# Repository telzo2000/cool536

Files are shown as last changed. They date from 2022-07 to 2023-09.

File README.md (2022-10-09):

# cool536
## What is cool536？

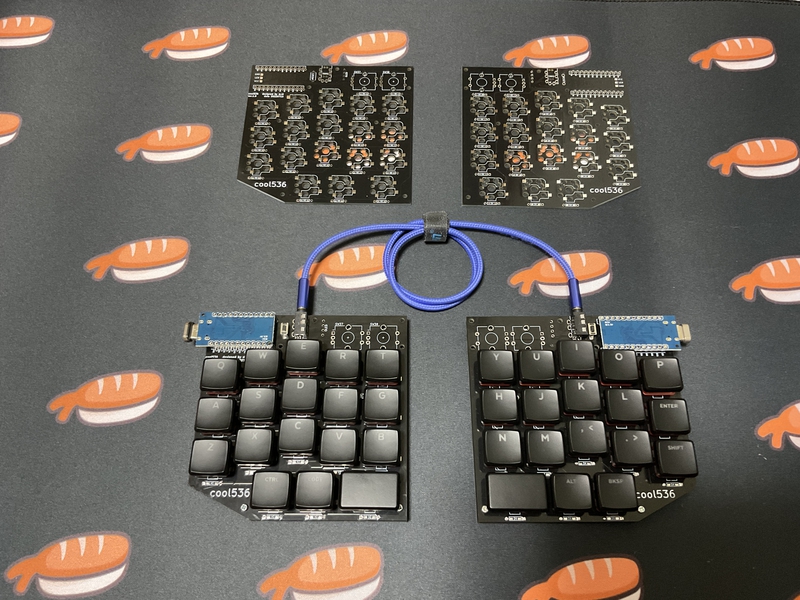
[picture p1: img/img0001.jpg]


The coo536 is a 36-key split keyboard.
<br>
The key layout is column staggered.
<br><br>
coo536は36キーの分割キーボードです。
<br>
キーレイアウトは、カラムスタッガードです。
<br><br>
You can choose either choc switch or cherry mx switch to use.
<br>
Chocスイッチか CHERRY MXスイッチのどちらか一つを選んで使うことができます。
<br>
<br>
Up to 4 rotary encoders can be installed. It is also possible to take an OLED display.
<br><br>
ロータリーエンコーダーを最大4個取り付けることが可能です。また、OLEDディスプレイも取りけることが可能です。
<br>

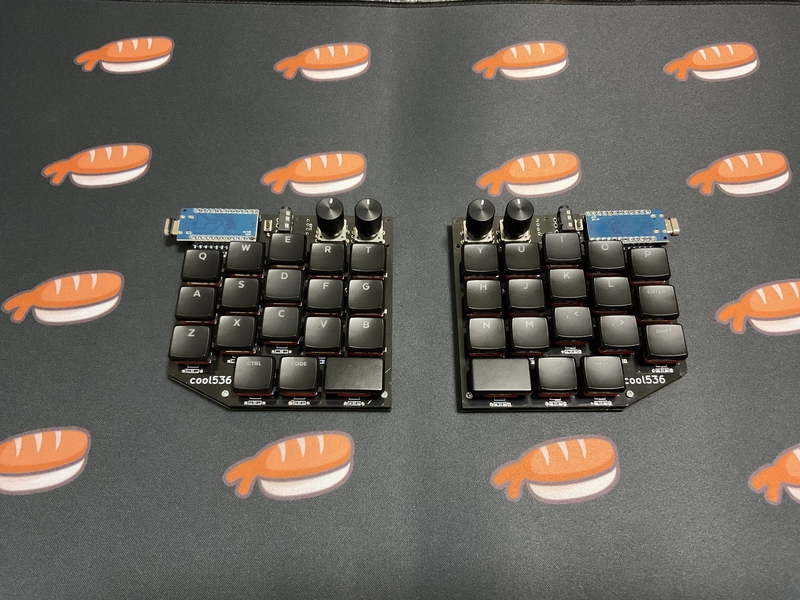
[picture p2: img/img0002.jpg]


<br>
In addition, it is now possible to attach a PIM447 trackball.
<br><br>
さらに、PIM447トラックボールを取り付けることも可能となりました。
<br>
<br>

[PIMORONI PIM447](https://shop.pimoroni.com/products/trackball-breakout?variant=27672765038675)

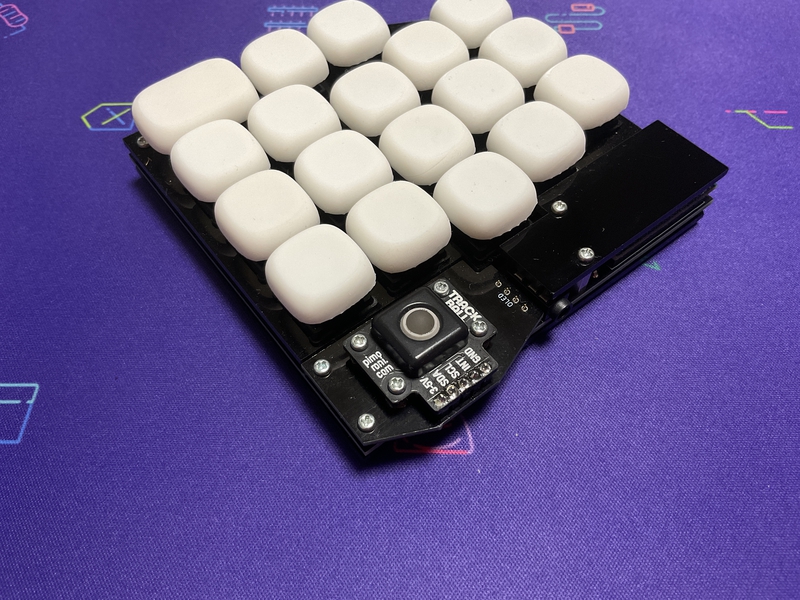
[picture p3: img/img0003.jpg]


<br>
The size of the PCB is within 100mmX100mm.
<br>
It will be distributed on booth in the future, but you can freely use the data here and place an order with the PCB manufacturer.
<br><br>
PCBのサイズは、100mmX100mm以内です。
<br>
将来、boothにて頒布しますが、ここにあるデータを自由に使い、各自がPCB製造元に発注しても構いません。
<br><br>
I do not take any responsibility for the data that you freely use.
<br>
Please use at your own risk.
<br><br>
各自が自由に使ったデータについては、私は一切の責任を負いません。
<br>
自己責任で利用してください。
<br>

## Booth
https://booth.pm/ja/items/4190386

## Build Guide
https://github.com/telzo2000/cool536/blob/main/buildguide_for_cool536.md
<br>

<br>

## Firmware
https://github.com/telzo2000/cool536/tree/main/firmware

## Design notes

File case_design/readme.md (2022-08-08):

The design difference between ver.1.00 and 1.10 is the position of the screw holes in the cover plate.
<br>
ver.1.00と1.10のデザインの違いは、カバープレートのネジ穴の位置が違うことです。
<br>
<br>
From ver.1.10 onwards, the positions of the screw holes on the cover plate have the same design.
<br>
ver.1.10以降は、カバープレートのネジ穴の位置は同じデザインです。
<br>

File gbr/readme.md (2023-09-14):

# gerber file 
<br>

# change history

Ver.1.40 Compatible with [AZ1UBALL](https://booth.pm/ja/items/4202085).
<br>

ver.1.40 [AZ1UBALL](https://booth.pm/ja/items/4202085)に対応。

<br><br>
The PIM447trackball parts are divided into left and right.
<br>
PIM447トラックボール部品は左右に分けました。
<br><br>
ver.1.30 I2C communication failed. Maybe the firmware will fix it.
<br>
ver.1.30 I2C通信をしたが、失敗。多分、ファームウェアで解決する。
<br><br>
ver.1.20　Enlarged screw holes on the pcb.A spacer is passed through from the switch plate to the bottom plate.
<br>
ver.1.20　pcbのネジ穴の拡張した。スイッチプレートからボトムプレートまでスペーサーを通す形式にした。
<br><br>
Ver.1.12　Corresponds to the problem of contact with the PCB wiring due to excessive tightening of the spacer.
<br>
Ver.1.12　スペーサーの締め付け過ぎにより、PCBの配線に接触不具合に対応。
<br><br>
Ver.1.10　Review the screw hole position of the cover plate.
<br>
Ver.1.10　カバープレートのネジ穴位置の見直し。
<br><br>
Ver.1.00　release.
<br>
Ver.1.00　リリース。
<br><br>

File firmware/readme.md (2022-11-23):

If you don't need a rotary encoder,
<br>
<br>
ロータリーエンコーダが不要な場合、
<br>
<br>
https://github.com/telzo2000/cool536/tree/main/firmware/firmware_cool536/cool536<br>
<br>
[remap](https://remap-keys.app)に対応済み。
<br>
<br>
<br>
If you need a rotary encoder,
<br>
<br>
ロータリーエンコーダが必要な場合、
<br>
<br>
https://github.com/telzo2000/cool536/tree/main/firmware/firmware_cool536r<br>
<br>
[remap](https://remap-keys.app)に対応済み。
<br>
<br>
If you need a trackball,
<br>
<br>
トラックボールが必要な場合、
<br>
<br>
https://github.com/telzo2000/cool536/tree/main/firmware/firmware_cool536r<br>
<br>
<br>
[remap](https://remap-keys.app)に対応済み。

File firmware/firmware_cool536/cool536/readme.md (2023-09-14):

# cool536

cool536

*A short description of the keyboard/project*

* Keyboard Maintainer: [m.ki](https://github.com/m.ki)
* Hardware Supported: *The PCBs, controllers supported*
* Hardware Availability: *Links to where you can find this hardware*

Make example for this keyboard (after setting up your build environment):

    make cool536:default

Flashing example for this keyboard:

    make cool536:default:flash

See the [build environment setup](https://docs.qmk.fm/#/getting_started_build_tools) and the [make instructions](https://docs.qmk.fm/#/getting_started_make_guide) for more information. Brand new to QMK? Start with our [Complete Newbs Guide](https://docs.qmk.fm/#/newbs).

## Bootloader

Enter the bootloader in 3 ways:

* **Bootmagic reset**: Hold down the key at (0,0) in the matrix (usually the top left key or Escape) and plug in the keyboard
* **Physical reset button**: Briefly press the button on the back of the PCB - some may have pads you must short instead
* **Keycode in layout**: Press the key mapped to `QK_BOOT` if it is available

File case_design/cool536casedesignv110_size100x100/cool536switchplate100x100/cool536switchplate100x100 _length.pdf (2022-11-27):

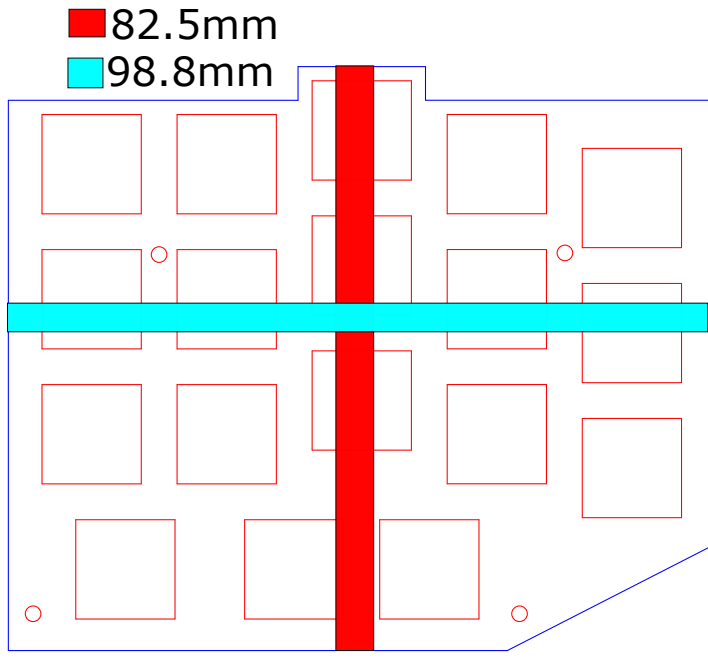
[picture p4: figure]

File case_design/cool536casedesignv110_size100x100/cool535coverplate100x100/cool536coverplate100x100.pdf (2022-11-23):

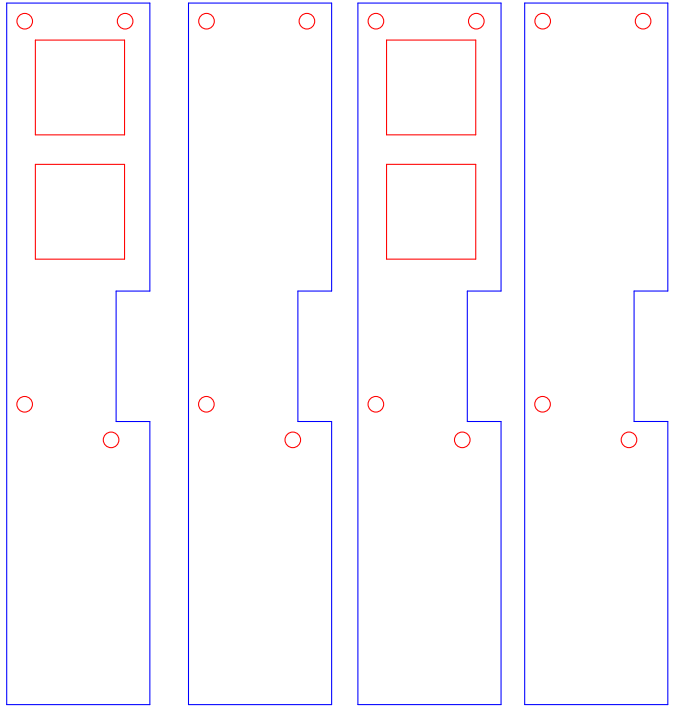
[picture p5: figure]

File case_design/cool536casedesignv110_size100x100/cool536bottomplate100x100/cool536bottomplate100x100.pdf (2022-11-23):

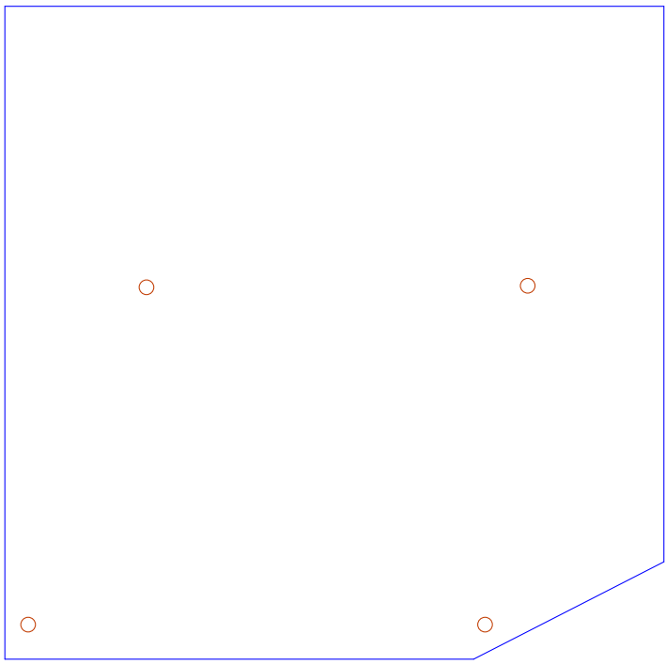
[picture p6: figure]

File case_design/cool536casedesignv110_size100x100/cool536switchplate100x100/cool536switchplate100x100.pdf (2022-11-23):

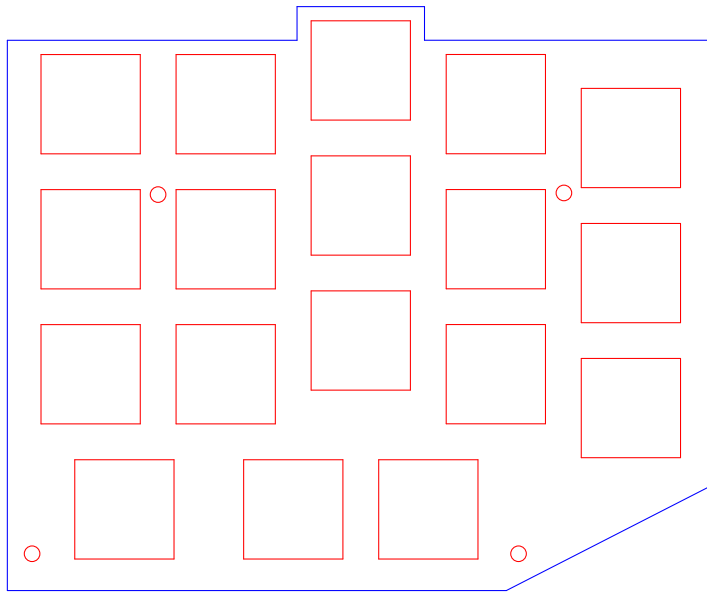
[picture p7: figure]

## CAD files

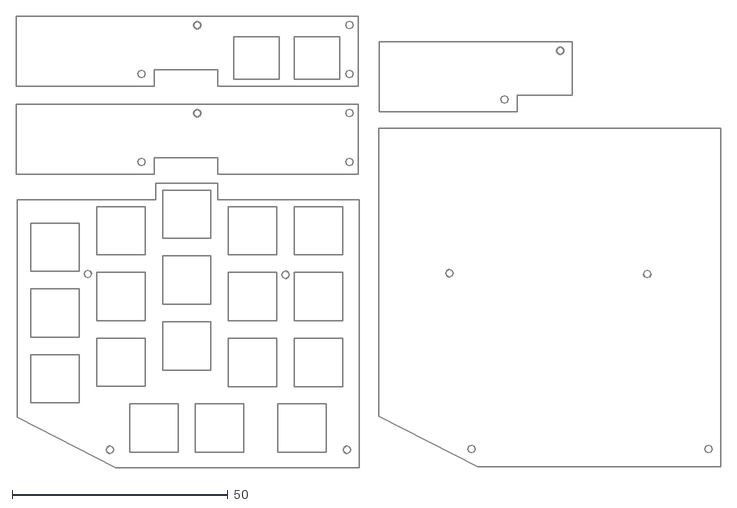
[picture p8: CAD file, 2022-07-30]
case_design/cool536casedesignv100/cool536casedesign200x300.dxf
163.1 x 104.5

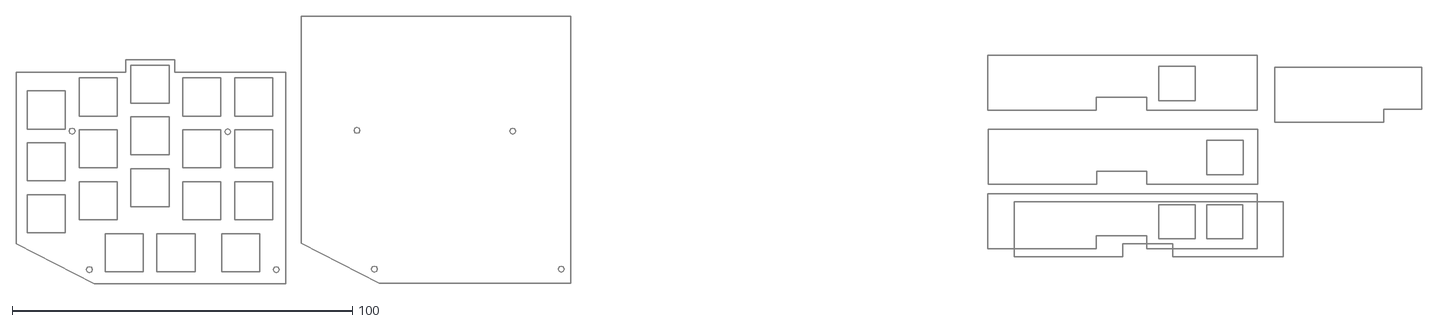
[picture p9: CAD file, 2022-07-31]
case_design/cool536casedesignv110/cool536casedesign240x280.dxf
413.0 x 78.6

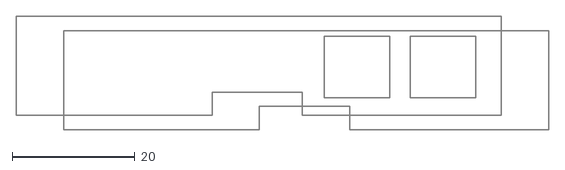
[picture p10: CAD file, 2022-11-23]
case_design/cool536casedesignv110_size100x100/cool535coverplate100x100/cool536coverplate100x100.dxf
86.9 x 18.5

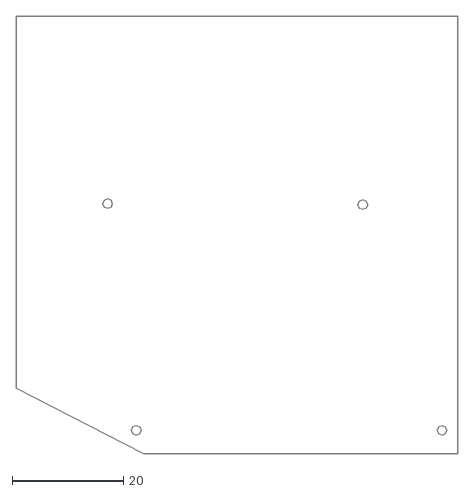
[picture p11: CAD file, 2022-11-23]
case_design/cool536casedesignv110_size100x100/cool536bottomplate100x100/cool536bottomplate100x100.dxf
79.2 x 78.4

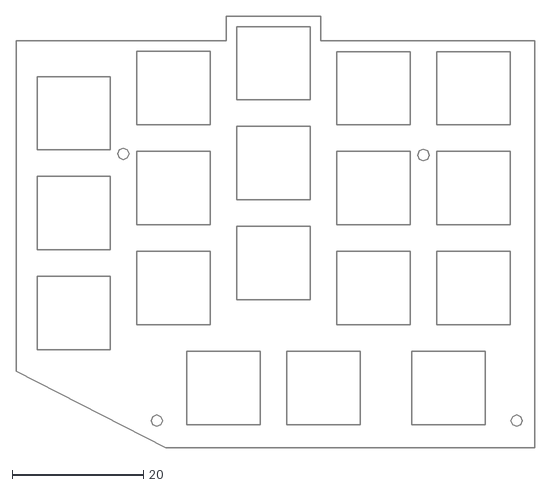
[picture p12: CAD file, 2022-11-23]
case_design/cool536casedesignv110_size100x100/cool536switchplate100x100/cool536switchplate100x100.dxf
79.2 x 65.9

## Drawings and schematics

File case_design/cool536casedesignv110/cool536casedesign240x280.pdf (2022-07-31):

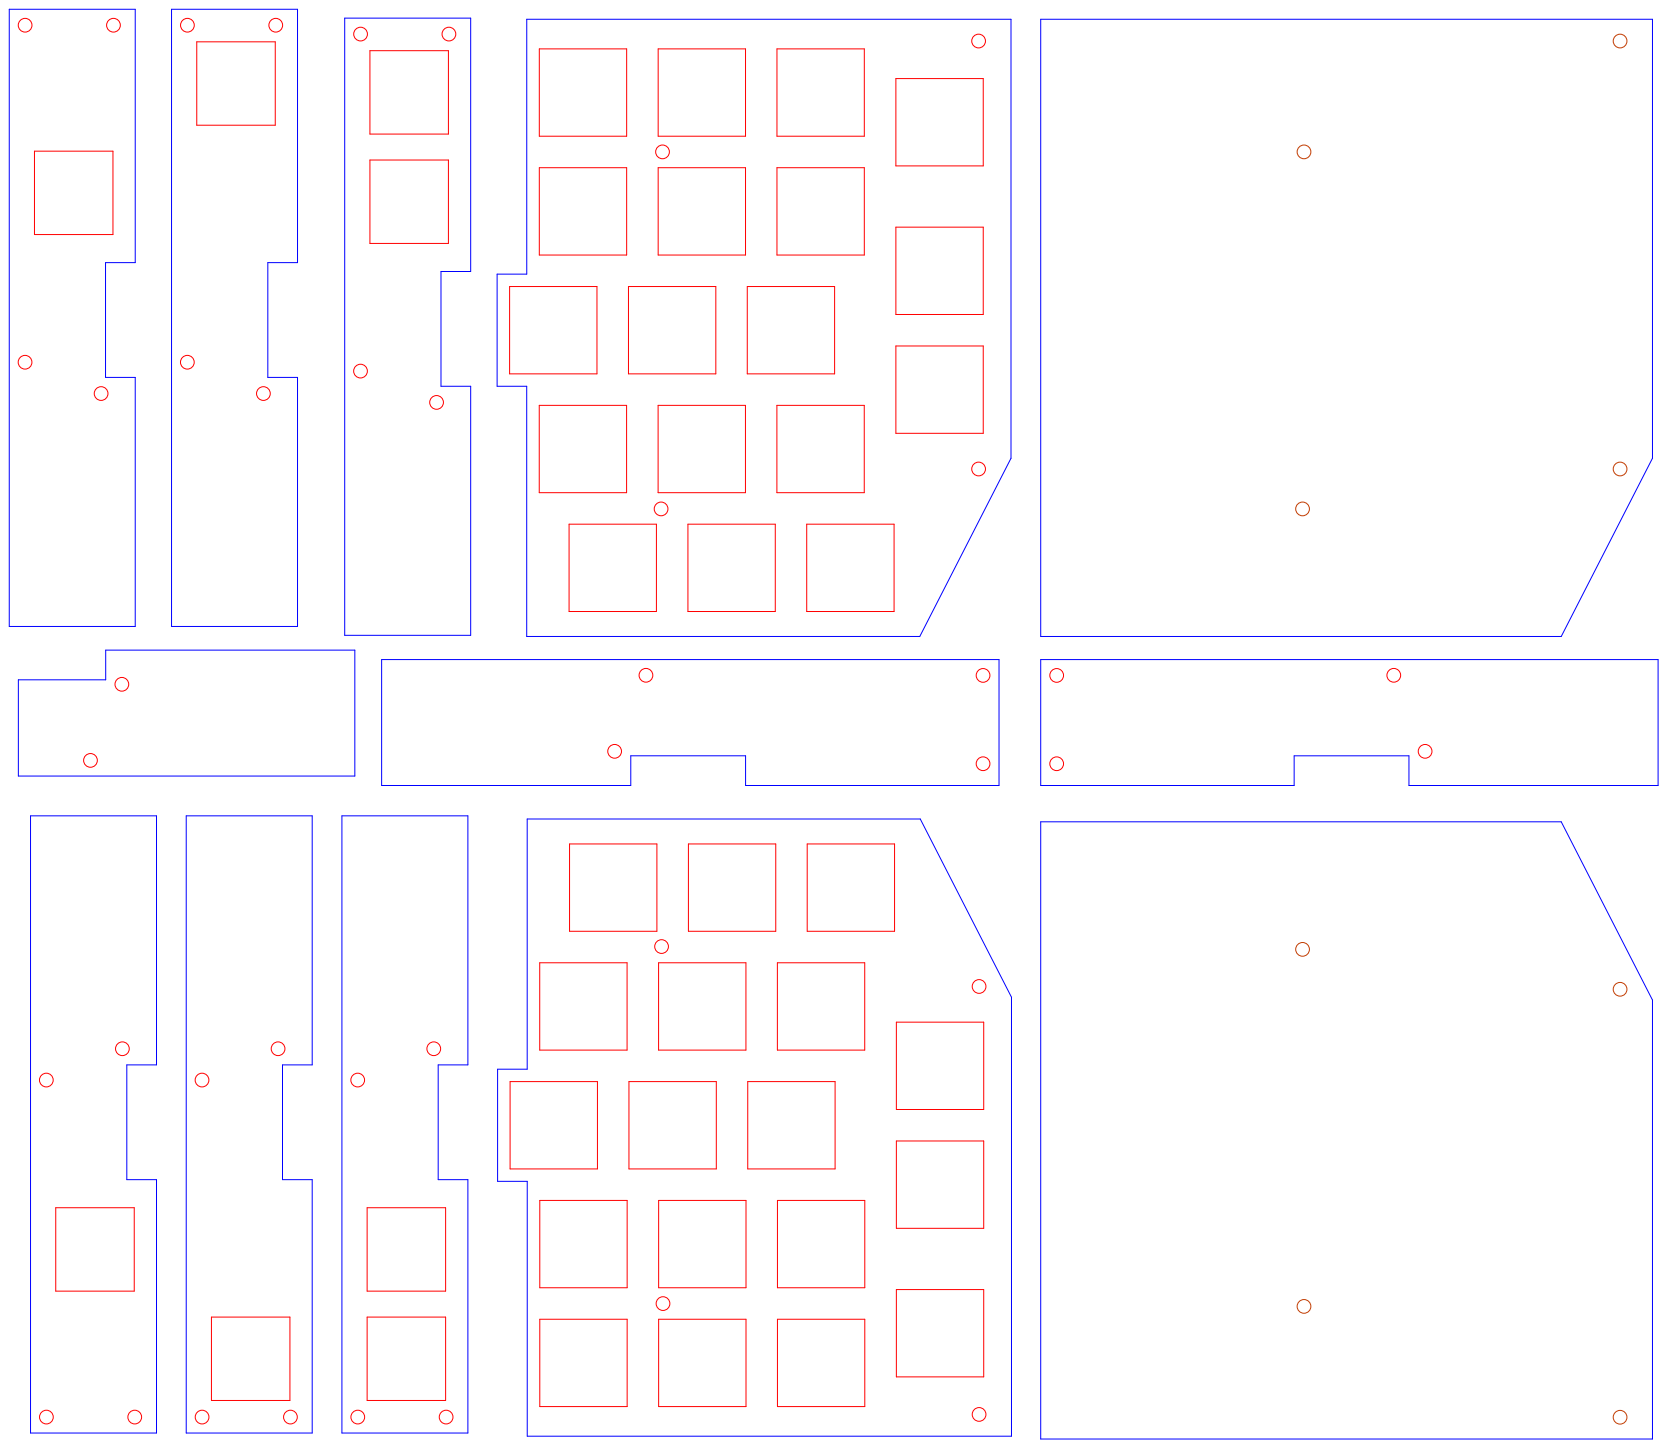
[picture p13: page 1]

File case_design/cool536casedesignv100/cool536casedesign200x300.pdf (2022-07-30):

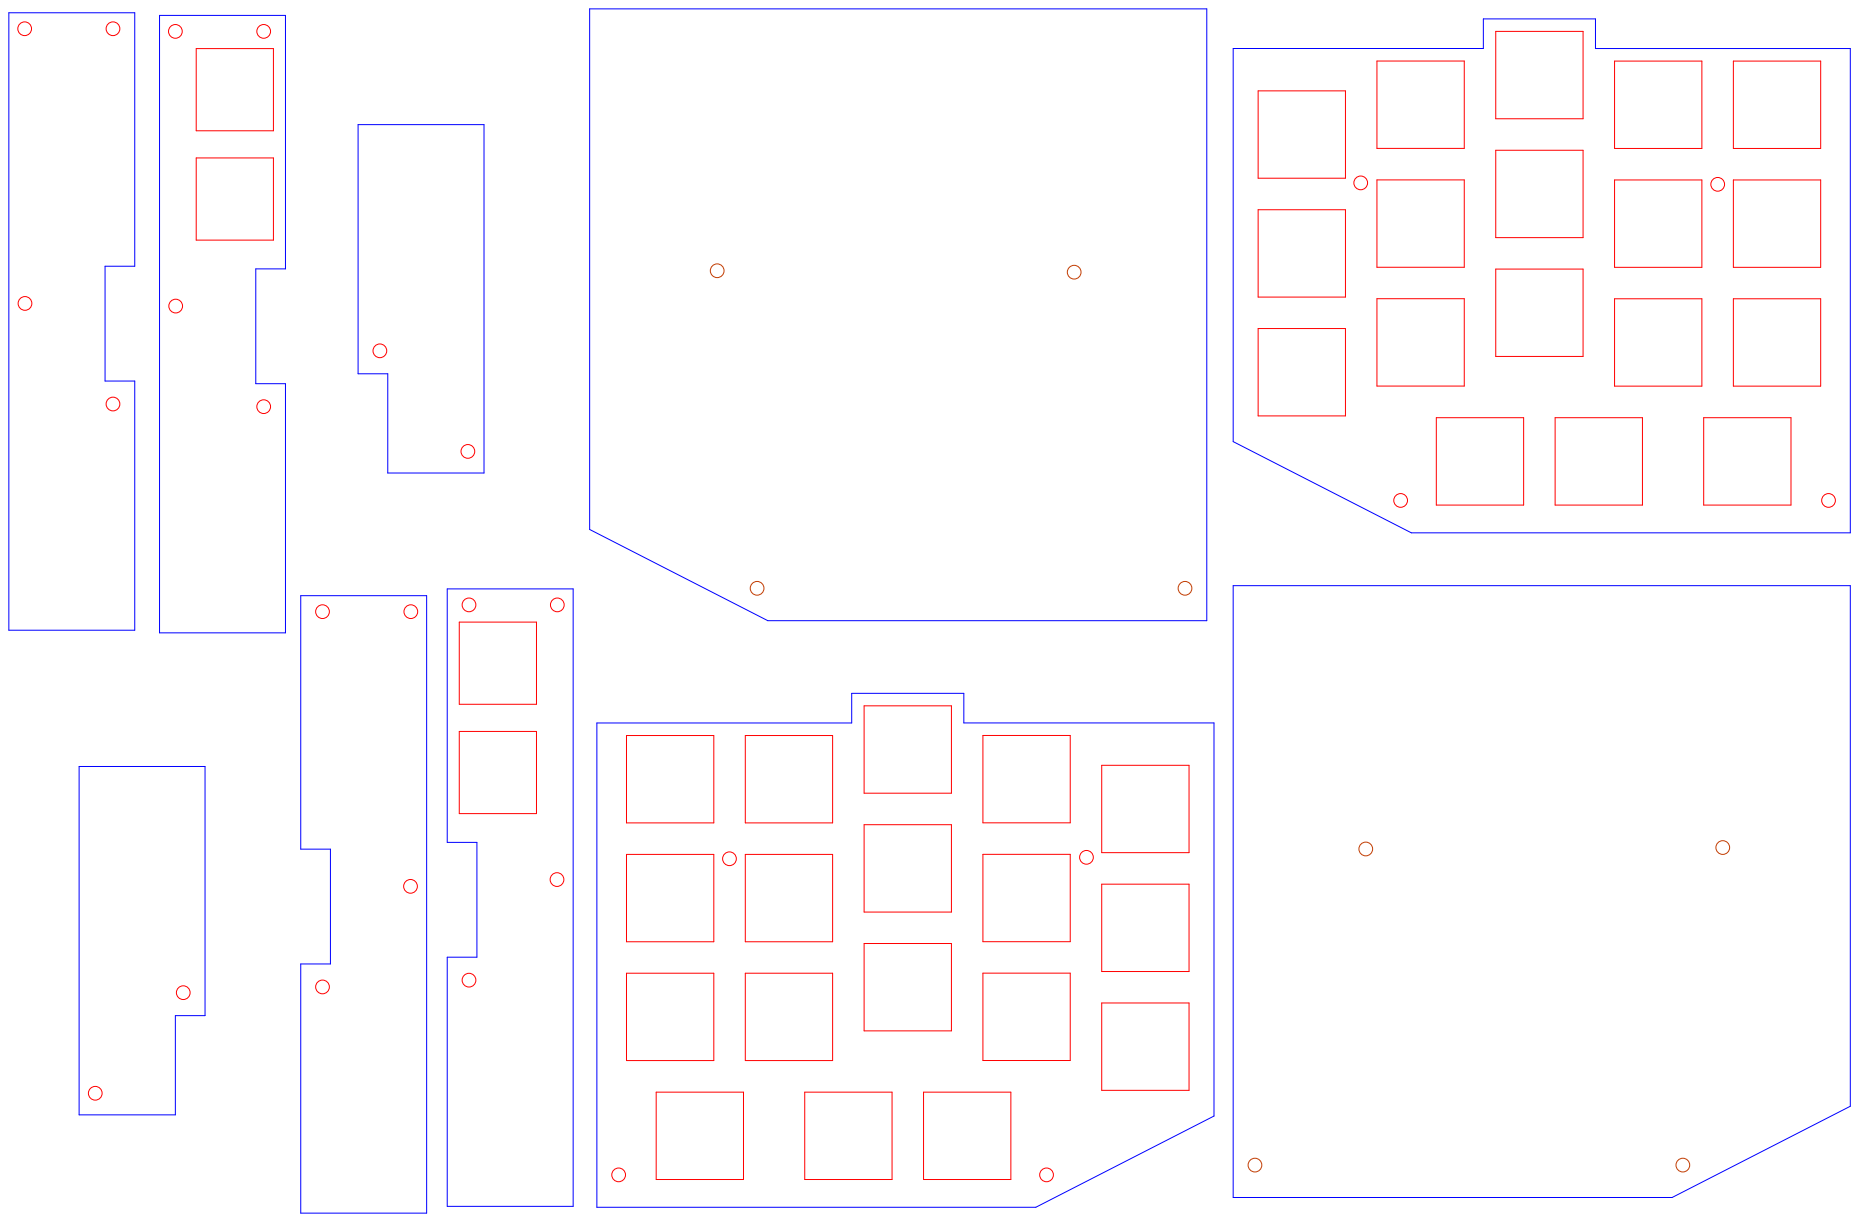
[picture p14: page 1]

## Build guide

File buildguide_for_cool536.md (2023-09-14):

# Build guide

## Parts list

| No. | Patrs | Quantity | remarks | Suppliers | Cost |
|--|--|--|--|--|--|
|番号|名前|数|備考|調達先|参考価格（送料込）|<br>
|1|PCB|2|40%splite keyboard|[elecrow](https://www.elecrow.com)<br>[JLCPCB](https://jlcpcb.com)<br>[ALLPCB](https://www.allpcb.com)|５枚で10〜20ドル|<br>
|2-1|Switch Plate<br>スイッチプレート|2|アクリル<br>[Plate data](https://github.com/telzo2000/cool536/tree/main/case_design)|[工房Emerge+](https://www.emergeplus.jp/laser-cutting-service/contact/)<br>[遊舎工房](https://yushakobo.jp)<br>[elecrow](https://www.elecrow.com)|種類による。|
|2-2|Cover Plate<br>カバープレート|2|↑|↑|↑|
|2-3|Bottom Plate<br>ボトムプレート|2|↑|↑|↑|
|3|M2screw<br>M2ネジ|16|4mm<br>CoverPlateで使用<br>3mmでも代用可|DIYショップなど|10本で100円程度|
|4|M2screw<br>M2ネジ|8|3mm<br>BottomPlateで使用|↑|↑|
|5A|M2screw<br>M2ネジ|8|8mm<br>MXスイッチ使用時SwitchPlateで使用|↑|↑|
|5B|M2screw<br>M2ネジ|8|6mm<br>chocスッチ使用時SwitchPlateで使用|↑|↑|
|6A|M2spacer<br>M2スペーサー|16|3mmメス-メス<br>MXスイッチ使用時|[ヒロスギネット](https://www.hirosugi-net.co.jp/shop/c/c10/)<br>[遊舎工房](https://yushakobo.jp)|20本で800円程度|
|6B|M2spacer<br>M2スペーサー|8|3mmメス-メス<br>chocスイッチ使用時|[ヒロスギネット](https://www.hirosugi-net.co.jp/shop/c/c10/)<br>[遊舎工房](https://yushakobo.jp)|20本で800円程度|
|7|M2spacer<br>M2スペーサー|8|8mmメス-メス<br>CoverPlateで使用|[ヒロスギネット](https://www.hirosugi-net.co.jp/shop/c/c10/)<br>[遊舎工房](https://yushakobo.jp)|20本で800円程度|
|8|pro micro|2|ピンヘッダも別途購入|[遊舎工房](https://yushakobo.jp)<br>[Talp Keyboard](https://talpkeyboard.net)<br>[Daily Craft Keyboard](https://shop.dailycraft.jp)等|価格変動中|
|9A|Swith socket<br>スイッチソケット|36|cherry MX互換|[遊舎工房](https://yushakobo.jp)<br>[Talp Keyboard](https://talpkeyboard.net)<br>[Daily Craft Keyboard](https://shop.dailycraft.jp)等|10個で165円程度|
|9B|Swith socket<br>スイッチソケット|36|choc互換|[遊舎工房](https://yushakobo.jp)<br>[Talp Keyboard](https://talpkeyboard.net)<br>[Daily Craft Keyboard](https://shop.dailycraft.jp)等|10個で165円程度|
|10|Diode<br>ダイオード|40|リードタイプでもSMDでも可|[遊舎工房](https://yushakobo.jp)<br>[Talp Keyboard](https://talpkeyboard.net)<br>[Daily Craft Keyboard](https://shop.dailycraft.jp)等|100個で220円程度から|
|11|タクトスイッチ|2|２本足のもの|[遊舎工房](https://yushakobo.jp)<br>[Talp Keyboard](https://talpkeyboard.net)<br>[Daily Craft Keyboard](https://shop.dailycraft.jp)等|１個11円程度|
|12|TRRSジャック|2|MJ-4PP-9|[遊舎工房](https://yushakobo.jp)<br>[Talp Keyboard](https://talpkeyboard.net)<br>[Daily Craft Keyboard](https://shop.dailycraft.jp)等|１個55円|

In addition, you will need a TRRS cable, USB cable, keycaps, etc.
<br>
この他に、TRRSケーブル、USBケーブル、キーキャップ等が必要です。
<br>
For ver.1.20 PCB, 4 M2spacer 8mm are required instead of 6A, and 4 M2spacer 5mm are required instead of 6B.
<br>
ver.1.20のPCBでは、6Aの代わりにM2spacer8mmを４本、6Bの代わりにM2spacer5mmを４本、必要となります。
<br>

## Firmware

###  QMK_FIRMWARE
[Here](https://github.com/telzo2000/cool536/tree/main/firmware)

<br>
[remap](https://remap-keys.app/)

<br>

## Build 1(PCB only)

### 1 Parts check

The cool536 is a PCB that uses both the front and back sides for left and right PCBs.
<br>
The part where the corner is cut diagonally will be the outside of the left and right.
<br>
<br>
cool536は左右のPCBに対して、表裏両面を使用するPCBです。
<br>
角が斜めにカットされている箇所が、左右の外側になります。
<br>

### 2 Diode soldering

Solder the diodes to the back of each of the left and right.
<br>
左右それぞれの裏面にダイオードのハンダ付けをします。
<br>

There are lead type and SMD diodes.
<br>
ダイオードはリードタイプか、SMDがあります。
<br>
Here, we will explain the lead type soldering.
<br>
ここでは、リードタイプのハンダ付けの説明をします。
<br>
However, those who adopt the choc switch should use SMD diodes.
<br>
ただし、chocスイッチを採用する人は、SMDのダイオードを使用してください。
<br>

Use a lead bender to bend the legs of the diode.
<br>
リードベンダーを使い、ダイオードの足を曲げます。
<br>

Insert the diode into the board.
<br>
ダイオードを基板に挿しこみます。
<br>

Please pay attention to the orientation of the diode.
<br>
ダイオードの向きに注意してください。
<br>

Secure the diode with masking tape, then face up.
<br>
マスキングテープでダイオードを固定してから、表面を上にします。
<br>
Solder the protruding legs.
<br>
はみ出ている足部分に、ハンダ付けをします。
<br>
After soldering, use nippers to cut off the protruding legs.
<br>
はんだ付けが終わったら、はみ出ている足をニッパーで切り取ってください。
<br>

[８倍速　Diodeハンダ付け動画](https://youtu.be/Yaodh2-XxV4)

<br>
<br>

### 3 Soldering switch sockets

Solder the switch sockets on the back side.
<br>
裏面にスイッチソケットのハンダ付けをします。
<br>
cool536 is compatible with both choc and cherry MX switches.
<br>
cool536はchocスイッチとcherryMXスイッチの両方に対応しています。
<br>
Both can be installed.
<br>
両方を取り付けることが可能です。
<br>
Here, solder the cherryMX switch.
<br>
ここでは、cherryMXスイッチのハンダ付けを行います。
<br>
Place the switch socket so that the letters MX are hidden.
<br>
MXという文字が隠れるように、スイッチソケットを乗せてください。
<br>
That is the correct switch socket orientation.
<br>
それが正しいスイッチソケットの向きになります。
<br>
When using a choc switch, place the switch socket so that the letters choc are hidden.
<br>
chocスイッチの時は、chocという文字が隠れるように、スイッチソケットを乗せてください。
<br>

Apply solder to both pads.
<br>
両方のパッドにハンダを盛ります。
<br>
Place the switch socket and fix it with a warm soldering iron while melting the solder.
<br>
スイッチソケットを乗せて、温めたハンダゴテで、ハンダを溶かしながら、固定します。
<br>
You can make it easier by working while holding it with tweezers.
<br>
ピンセットで押さえながら、作業をすると楽にできます。
<br>

[８倍速　Switch socketハンダ付け動画](https://youtu.be/E__mHvmIXQo)

<br><br>

### 4 Soldering reset switch & TRRS jack 

Insert the reset switch on the surface.
<br>
表面にリセットスイッチを挿しこみます。
<br>
Solder the legs of the reset switch from the back.
<br>
裏面からリセットスイッチの足をハンダ付けします。
<br>
Solder the TRRS jack in the same way near the reset switch.
<br>
TRRSジャックは、リセットスイッチの近くに同じようにハンダ付けします。
<br>
Insert the left and right TRRS jacks from the front side and solder from the back side.
<br>
TRRSジャックは左右１箇所ずつ、表面から差し込み、裏面からはんだ付けをしてください。
<br>

[８倍速　Reset switch,TRRS jackハンダ付け動画](https://youtu.be/3gEbExaOAv4)

<br><br>

### 5　Pro micro 

cool536 requires pro micro on each side.
<br>
cool536は左右それぞれにpro microが必要となります。
<br>

Use the conthrough to fix the pro micro with the side with the parts facing down.
<br>
pro microの部品のある面を下向きに、コンスルーを使い、固定してください。
<br>

Pay attention to the orientation of the conthrough.
<br>
コンスルーの向きに注意してください。
<br>

<br>

### 6　Test

Please write the firmware and check the operation.
<br>
ファームウェアを書き込んで、動作確認をしてください。
<br>

Install a switch or measure continuity with tweezers, etc.
<br>
スイッチを取り付けるか、ピンセット等で導通をはかるかを行います。
<br>

<br>

### QMK_FIRMWARE
[Here](https://github.com/telzo2000/cool536/tree/main/firmware)

<br>
[remap](https://remap-keys.app/)
<br>
<br>

### 7 Installation of key switch

Attach your favorite key switch.
<br>
好きなキースイッチを取り付けてください。
<br>

<br>
If you like, attach a rubber cushion to the back and you're done.
<br>
お好みで裏面にラバークッションを取り付けたら、完成です。
<br>
<br>
<br>

### Option 1 Installing a rotary encoder

cool536 can be equipped with 1 to 2 rotary encoders on the left and right, for a total of 4 rotary encoders.
<br>
cool536は、左右に１〜２個、合計４個のロータリーエンコーダーを取り付けることができます。
<br><br>

### Option 2 Mounting the OLED display

The left side of the cool536 can be fitted with an OLED display.
<br>
In that case, the rotary encoder cannot be attached to the left side of the cool536.
<br>
cool536の左側には、OLEDディスプレイを取り付けることができます。
<br>
その場合、cool536の左側には、ロータリーエンコーダーを取り付けることができません。
<br>
<br>

### OPtion 3 Installing PIM447 Trackball

You can install the PIM447 on either the left or right side.
<br>
In that case, you will need trackballpart.
<br><br>
左右どちらでも、PIM447を取り付けることができます。
<br>
その時は、trackballpartが必要となります。
<br>
<br>
In addition to PIM447 and trackballpart, you will need １２ M2 screws, 6 M2 spacers 3mm, and a pin header.
<br><br>
PIM447とtrackballpartの他に、M2ネジ3mm12本、M2スペーサー3mm６個、ピンヘッダが必要となります。
<br><br>

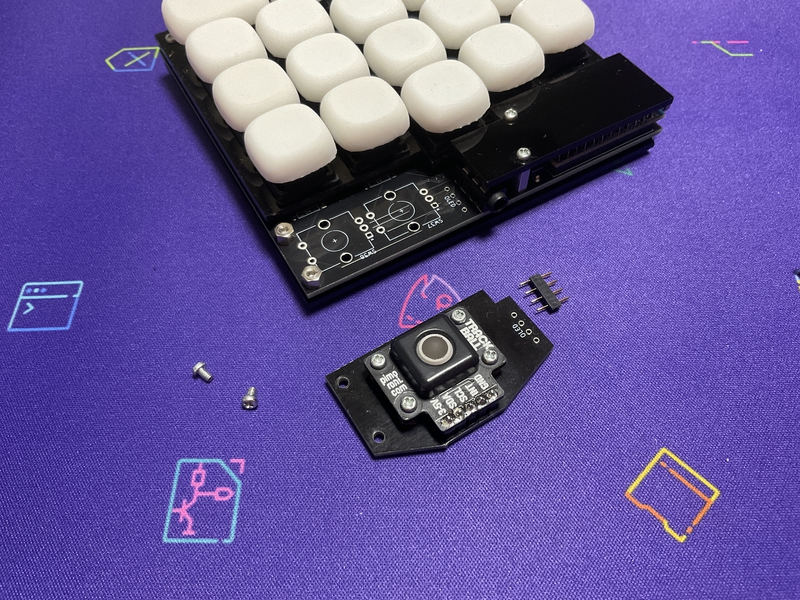
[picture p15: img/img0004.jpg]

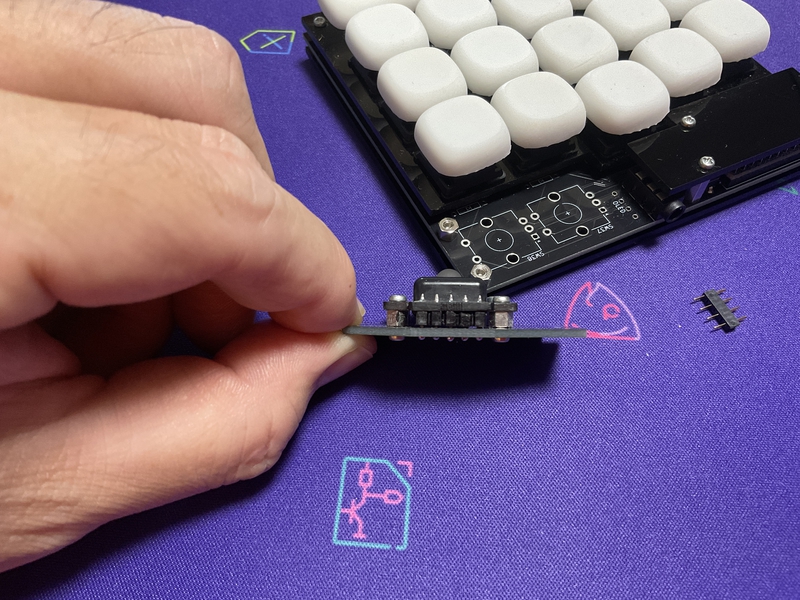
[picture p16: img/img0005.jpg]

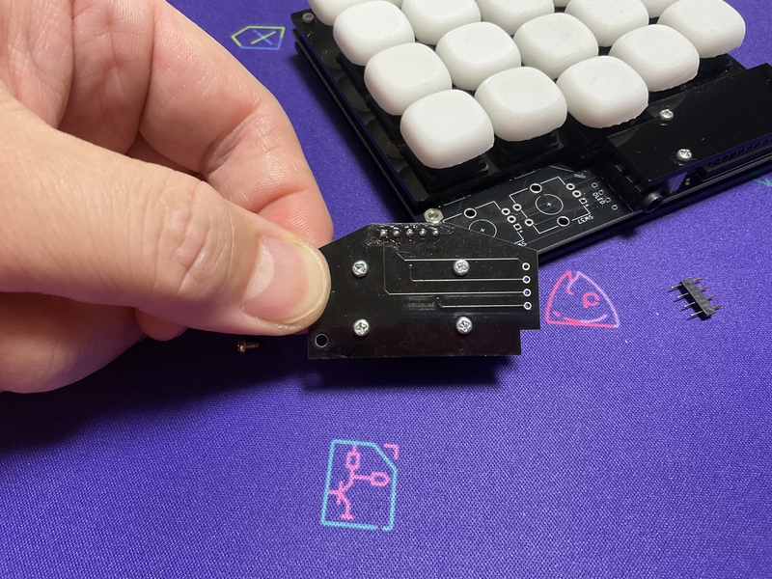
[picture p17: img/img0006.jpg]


<br><br><br>

## Build 2(Acrylic sandwich mount case)



After 1 ~ 6 of build1, please do the next step.
<br>
build1の1~6の後、次の工程をしてください。
<br>

### 1 Installation of cover plate

Prepare a cover plate, M2 spacer 8mm（x４）, and M2 screw 4mm（x８）.
<br>
カバープレート、M2スペーサー6mm（４個）、M2ネジ3mm（８本）を用意します。
<br>
Screw the spacer to the cover plate in the same orientation.
<br>
カバープレートに同じ向きで、スペーサーをネジで固定します。
<br>
Then use the remaining screws to attach the cover plate to the PCB.
<br>
次に、残りのネジを使い、カバープレートをPCBに取り付けます。
<br>
There is an orientation of the cover plate, so it is good to check it once before starting work.
<br>
カバープレートの向きがあり、作業前に一度、重ねて確認すると良いです。
<br>
<br>
A special cover plate is required when installing a rotary encoder or an OLED display.
<br>
ロータリーエンコーダーまたはOLEDディスプレイを取り付けているとき、専用のカバープレートが必要となります。
<br><br>

### 2-1 Installation of switch plate（choc switch）

Prepare a switch plate, M2 spacer 3 mm（x４）, and M2 screw 6 mm（x４）.
<br>
スイッチプレート、M2スペーサー３mm（４本）、M2ネジ６mm（４本）を用意します。
<br>
Fix the screws in 4 places.
<br>
ネジを４箇所、固定します。
<br>
Insert the screws in the order of the switch plate and the PCB, and fix them with spacers on the back of the PCB.
<br>
ネジはスイッチプレート、PCBの順でさしこみ、PCBの裏面でスペーサーで固定します。
<br>

<br>

### 2-2 Installation of switch plate（cherry MX switch）

Prepare a switch plate, M2 spacer 3 mm（x８）, and M2 screw 8 mm（x４）.
<br>
スイッチプレート、M2スペーサー３mm（８本）、M2ネジ８mm（４本）を用意します。
<br>
Fix the screws in 4 places.
<br>
ネジを４箇所、固定します。
<br>
Insert the switch plate into the screw and fix it with a spacer.
<br>
ネジはスイッチプレートをさしこみ、スペーサーで固定します。
<br>
Next, insert the switch plate into the PCB and secure it with a spacer on the back of the PCB.
<br>
次に、スイッチプレートをPCBにさしこみ、PCBの裏面でスペーサーで固定します。
<br>

### 3 Installation of bottom plate 

Prepare the bottom plate and M2 ３mm screws（x４）.
<br>
ボトムプレート、M２ネジ３mm（４本）を用意します。
<br>
Place the bottom plate according to the spacer on the back of the PCB and fix it with screws.
<br>
PCB裏面にあるスペーサーに合わせて、ボトムプレートをのせて、ネジで固定します。
<br>
<br>
From here, proceed with step 7 of build1.
<br>
ここからは、build１の７の工程を進めてください。
<br>

Have a fun selfmade keyboard life!
<br>
楽しい自作キーボード生活を!

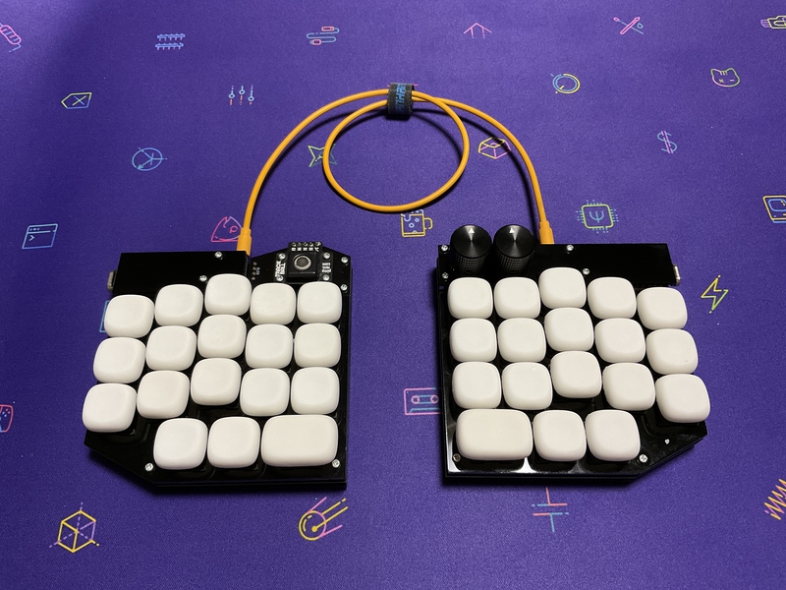
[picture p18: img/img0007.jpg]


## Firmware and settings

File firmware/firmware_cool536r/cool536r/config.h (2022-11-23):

// Copyright 2021 m.ki (@telzo2000)
// SPDX-License-Identifier: GPL-2.0-or-later

#pragma once

#include "config_common.h"

/* USB Device descriptor parameter */
#define VENDOR_ID    0x4D43
#define PRODUCT_ID   0x0537
#define DEVICE_VER   0x0001
#define MANUFACTURER m.ki
#define PRODUCT      cool536r

/* key matrix size */
#define MATRIX_ROWS 10
#define MATRIX_COLS 5

#define MATRIX_ROW_PINS { B5, B4, B1 , F7, D0 }
#define MATRIX_COL_PINS { B2, B6, B3, F6, F5 }
#define MATRIX_ROW_PINS_RIGHT { B5, B4, B1 , F7, D0 }
#define MATRIX_COL_PINS_RIGHT { B2, B6, B3, F6, F5  }
#define UNUSED_PINS

#define DIODE_DIRECTION ROW2COL

#define ENCODERS_PAD_A {D4,D7 }
#define ENCODERS_PAD_B {C6,E6 }
#define ENCODERS_PAD_A_RIGHT {D7,D4 }
#define ENCODERS_PAD_B_RIGHT {E6,C6}

#define MASTER_LEFT

#define SOFT_SERIAL_PIN D2
//#define SELCT_SOFT_SERIAL_SPEED {4}
//#define USE_I2C
#define MASTER_LEFT
#define SPLIT_OLED_ENABLE

#define SPLIT_USB_DETECT

#define RGB_DI_PIN D3
#ifdef RGB_DI_PIN
#    define RGBLED_NUM 16
#    define RGBLIGHT_HUE_STEP 8
#    define RGBLIGHT_SAT_STEP 8
#    define RGBLIGHT_VAL_STEP 8
#    define RGBLIGHT_LIMIT_VAL 255 /* The maximum brightness level */
#    define RGBLIGHT_SLEEP  /* If defined, the RGB lighting will be switched off when the host goes to sleep */
/*== all animations enable ==*/
#    define RGBLIGHT_ANIMATIONS
/*== or choose animations ==*/
//#    define RGBLIGHT_EFFECT_BREATHING
//#    define RGBLIGHT_EFFECT_RAINBOW_MOOD
//#    define RGBLIGHT_EFFECT_RAINBOW_SWIRL
//#    define RGBLIGHT_EFFECT_SNAKE
//#    define RGBLIGHT_EFFECT_KNIGHT
//#    define RGBLIGHT_EFFECT_CHRISTMAS
//#    define RGBLIGHT_EFFECT_STATIC_GRADIENT
//#    define RGBLIGHT_EFFECT_RGB_TEST
//#    define RGBLIGHT_EFFECT_ALTERNATING
/*== customize breathing effect ==*/
/*==== (DEFAULT) use fixed table instead of exp() and sin() ====*/
//#    define RGBLIGHT_BREATHE_TABLE_SIZE 256      // 256(default) or 128 or 64
/*==== use exp() and sin() ====*/
#    define RGBLIGHT_EFFECT_BREATHE_CENTER 1.85  // 1 to 2.7
#    define RGBLIGHT_EFFECT_BREATHE_MAX    255   // 0 to 255
#endif

/* Debounce reduces chatter (unintended double-presses) - set 0 if debouncing is not needed */
#define DEBOUNCE 5

/* define if matrix has ghost (lacks anti-ghosting diodes) */
//#define MATRIX_HAS_GHOST

/* Mechanical locking support. Use KC_LCAP, KC_LNUM or KC_LSCR instead in keymap */
#define LOCKING_SUPPORT_ENABLE
/* Locking resynchronize hack */
#define LOCKING_RESYNC_ENABLE

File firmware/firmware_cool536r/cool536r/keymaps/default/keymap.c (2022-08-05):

// Copyright 2022 m.ki (@telzo2000)
// SPDX-License-Identifier: GPL-2.0-or-later

#include QMK_KEYBOARD_H

// Defines names for use in layer keycodes and the keymap
enum layer_names {
  _QWERTY,
    _LOWER,
    _RAISE,
    _ADJUST,
};

// Defines the keycodes used by our macros in process_record_user
enum custom_keycodes {
    QWERTY = SAFE_RANGE,
    LOWER,
    RAISE,
    ADJUST,
};

const uint16_t PROGMEM keymaps[][MATRIX_ROWS][MATRIX_COLS] = {
    
    [_QWERTY] = LAYOUT(
    KC_1,    KC_2,                                                                                  KC_3,    KC_4,
    KC_Q,    KC_W,    KC_E,    KC_R,    KC_T,               KC_Y,               KC_U,     KC_I,     KC_O,    KC_P,    
    KC_A,    KC_S,    KC_D,    KC_F,    KC_G,               KC_H,               KC_J,     KC_K,     KC_L,    KC_ENT,    
    KC_Z,    KC_X,    KC_C,    KC_V,    KC_B,               KC_N,               KC_M,     KC_COMM,  KC_DOT,  KC_RSFT, 
                      KC_LCTL, KC_LGUI, LT(_LOWER,KC_SPACE),LT(_RAISE,KC_SPACE),KC_LALT, KC_BSPC
  ),
  
  [_LOWER] = LAYOUT(
    KC_1,     KC_2,                                                                                               KC_3,           KC_4,
    KC_1,     KC_2,      KC_3,      KC_4,      KC_5,                KC_6,                KC_7,     KC_8,          KC_9,           KC_0,    
    KC_EXLM,  KC_AT,     KC_HASH,   KC_DLR,    KC_PERC,             KC_CIRC,             KC_AMPR,  KC_ASTR,       KC_LPRN,        KC_RPRN, 
    KC_PPLS,  KC_PMNS,   KC_PAST,   KC_PSLS,   KC_PEQL,             KC_GRV,              KC_JYEN,  RSFT(KC_LBRC), RSFT(KC_RBRC),  RSFT(KC_MINS),
                         KC_ESC, KC_INSERT, LT(_LOWER,KC_SPACE),    KC_MINS,KC_LALT, KC_BSPC
  ) ,
  [_RAISE] = LAYOUT(
    KC_1,     KC_2,                                                                                               KC_3,           KC_4,
    KC_F1,    KC_F2,      KC_F3,      KC_F4,          KC_F5,               KC_F6,               KC_F7,    KC_F8,     KC_F9,     KC_F10,    
    KC_AT,    KC_BSLS,    KC_SCLN,    RSFT(KC_SCLN),  KC_QUOT,             KC_LEFT,             KC_DOWN,  KC_UP,     KC_RIGHT,  KC_EQL,
    RGB_TOG,  RGB_MOD,    RGB_HUI,    RGB_HUD,        RGB_SAI,             RGB_SAD,             RGB_VAI,  KC_LBRC,   KC_RBRC,   KC_BSLASH,
                          KC_TAB,   KC_INSERT,  RSFT(KC_MINS), LT(_RAISE,KC_SPACE),KC_LALT, KC_BSPC
  ) 
};

bool encoder_update_user(uint8_t index, bool clockwise) {
    if (index == 0) { /* Left encoder left */
                if (clockwise) {
                    tap_code(KC_UP);
                } else {
                    tap_code(KC_DOWN);
                }
    } else if (index == 1) { /* Left encoder right */
                if (clockwise){
                    tap_code(KC_LEFT);
                } else {
                    tap_code(KC_RIGHT);
                }
    } else if (index == 2) { /* Right encoder left */
                if (clockwise) {
                      tap_code16(LCTL(KC_PPLS));
                } else {
                    tap_code16(LCTL(KC_PMNS));
                }
    } else if (index == 3) { /* Right encoder right */
                if (clockwise) {
                    tap_code16(KC_MS_WH_UP);
                } else {
                    tap_code16(KC_MS_WH_DOWN); 
                } 
            }
return true;
}

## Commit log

2022-08-07 配線修正
    [cool536-B_Cu.gbr, cool536-B_Mask.gbr, cool536-B_SilkS.gbr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]
2023-03-10 readme.md を更新
